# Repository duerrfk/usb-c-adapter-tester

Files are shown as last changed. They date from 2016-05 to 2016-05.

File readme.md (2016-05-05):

USB-C-Adapter-Tester is a device to test USB-C-to-USB-A/Micro-USB cables and adapters for conformity with the USB standard. Such USB-C adapters should use a 56k resistor connecting the 5 V line to the CC (Channel Configuration) line to signal to the downstream device (e.g., smartphone) that it should not draw more than standard USB power. However, some cables and adapters use smaller resistor values resulting in excessive current drawn by the downstream USB-C device, which might damage the upstream USB device providing power.

USB-C-Adapter-Tester consists of a hardware and a software part:

* circuit board (PCB) for connecting the USB-C cable/adapter under test 
* software based on the Arduino platform

Eagle files and PDFs for the hardware (schematics, board layout) can be found in folder `pcb`. The software can be found in folder `src`.

# Hardware

The tester hardware as depicted in the figures below consists of a microcontroller (Atmega 328p; same chip as the Arduino UNO) featuring an Analog-to-Digital Converter (ADC). The ADC measures the voltage drop along a 5.1k resistor (actually, two separate 5.1k resistors on different channels of the ADC since USB-C features two CC lines so you can plug-in the USB-C cable either way). Knowing the resistance and the voltage drop measured by the ADC, the microcontroller calculates the current (ICC) flowing on the CC line. If ICC is within the specified range (80 uA +- 20 % according to the standard), an LED signaling a "good" cable is turned on from an GPIO pin. If it is outside the range, another LED signaling a "bad" cable is turned on.

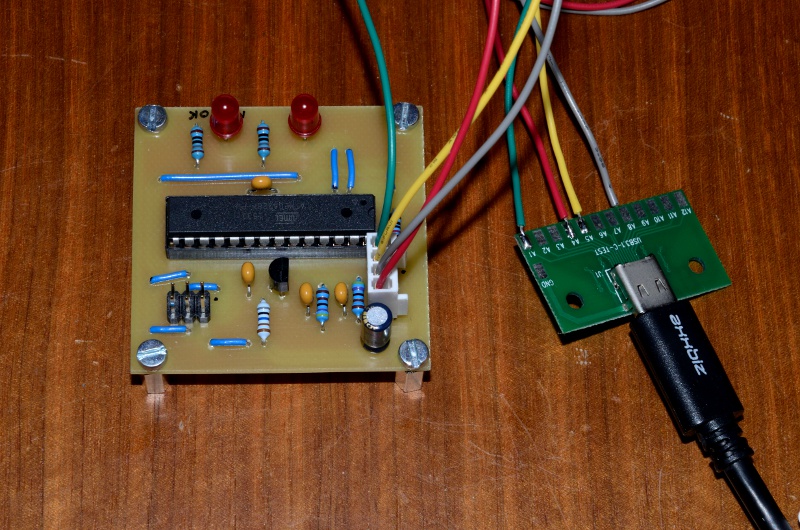
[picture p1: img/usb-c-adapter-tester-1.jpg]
USB-C Tester Device

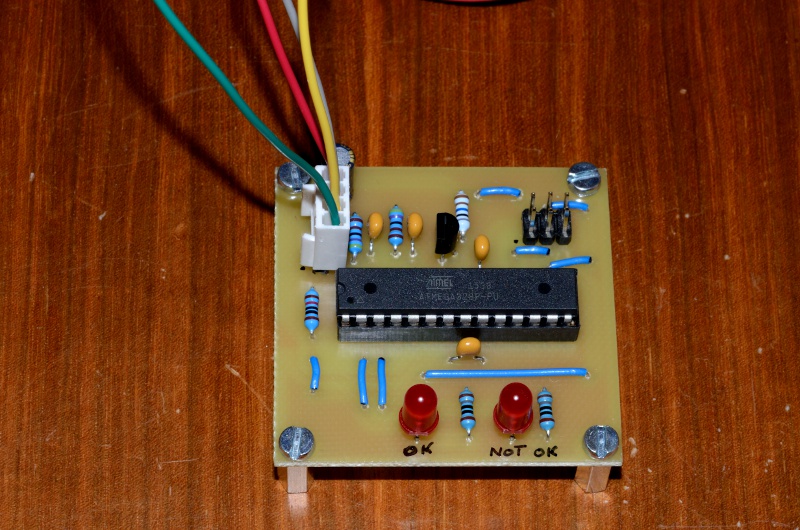
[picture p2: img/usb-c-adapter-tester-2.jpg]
USB-C Tester Device


The cable to be checked is connected to an USB host or charger to power the microcontroller. The good old Atmega 328p can be powered from 5V, which is the voltage provided by standard USB-A and Micro-USB. 

Since the internal voltage reference of the Atmega might not be very precise, an external 2.5 V voltage reference diode is used as reference for the ADC. 

As soon as the cable under test is plugged in, the microcontroller starts measuring the voltage drop along the 5.1k resistor using the ADC, translates the voltage to current (R = V/I), compares the measured current to the allowed current range (80 uA +- 20 %), and switches on the corresponding "good" or "bad cable" LED.

# Programming the Microcontroller

The code is implemented for the Arduino platform. 

The device is programmed through an in-system programmer port (6 pin ISP) with the following standard layout:

    MISO <-- 1 2 --> VCC
     SCK <-- 3 4 --> MOSI
     RST <-- 5 6 --> GND

To prepare the Atmega, program the following fuses (note that "0" means 
that the fuse is programmed):

* CKSEL = 0010: use internal 8 MHz RC oscillator
* CKDIV8 = 1: 8 MHz system clock (do not divide the 8 MHz internal clock by 8)
* SPIEN = 0: enable serial programming
* BODLEVEL = 101: brown-out detection set to 2.7 V
* SUT = 00: lowest possible startup time (6 CK from power-down; since we use
  BOD, we do not need additional waiting time for the power source to come up)
    
Using avrdude, the command looks like this (you might need
to execute this command as root):

    $ avrdude -c usbasp -p m328p -U lfuse:w:0xc2:m -U hfuse:w:0xd9:m -U efuse:w:0x05:m

Make sure to compile your code for the correct board (Atmega 328p at 8 MHz). In the repository, 
you will find a suitable board definition for the Arduino IDE (see folder 
`board_definition`). Copy the directory `atmega328_8MHz` into the folder 
`hardware` in your Arduino sketchbook. Then you should find and select the 
board  called `ATmega328P @ 8 MHz` under the menu item `Tools/Board`. 

Compiling generates a hex file that you need to program the Atmega. This hex 
file is a little hidden in the temporary build directory of the Arduino
IDE. If you use Linux  and Arduino IDE 1.6, have a look at the `/tmp` 
directory. After hitting the  compile button in the Arduino IDE, search for the
latest hex file called `usb-c-adapter-tester.cpp.hex` in a temporary directory named `/tmp/build...`. If you have found the hex file, you can flash it using avrdude (again, you might need to be root):

    $ avrdude -p m328p -c usbasp -v -U flash:w:/tmp/build6535101126624677692.tmp/usb-c-adapter-tester.cpp.hex

# Licensing

USB-C-Adapter-Tester uses two licenses for open hardware and software, respectively:

* The software (source code) is licensed under the Apache License 2.0
* The hardware (schematic diagrams, circuit board layouts, hardware documentation) is licensed under the CERN Open Hardware Licence v1.2

Both licenses are included in the repository.

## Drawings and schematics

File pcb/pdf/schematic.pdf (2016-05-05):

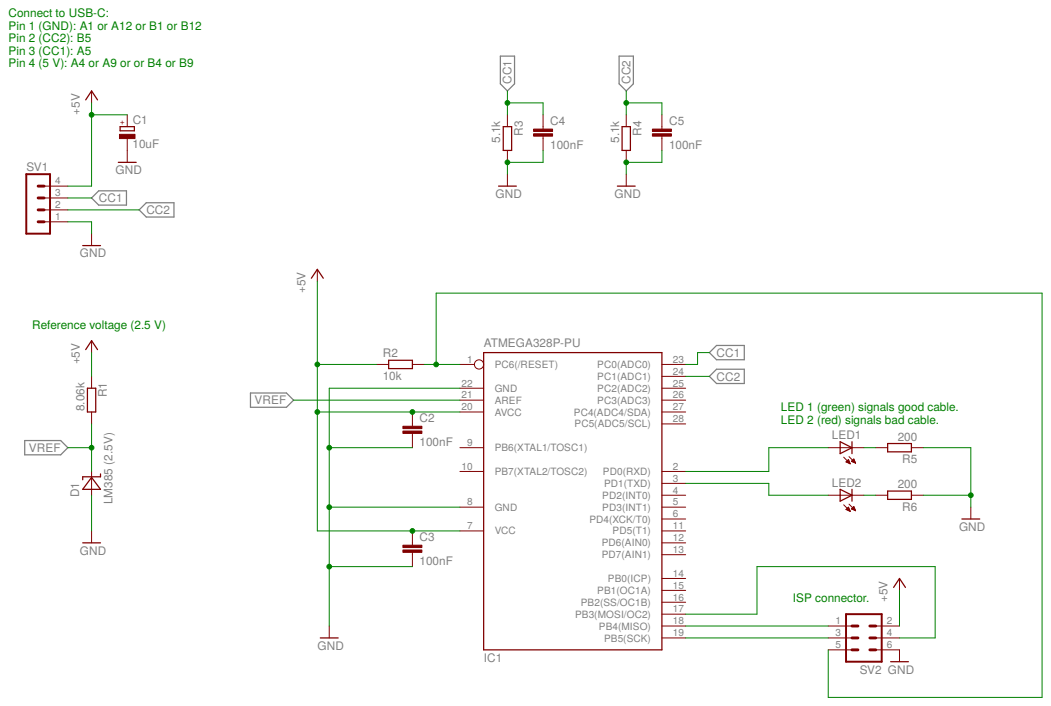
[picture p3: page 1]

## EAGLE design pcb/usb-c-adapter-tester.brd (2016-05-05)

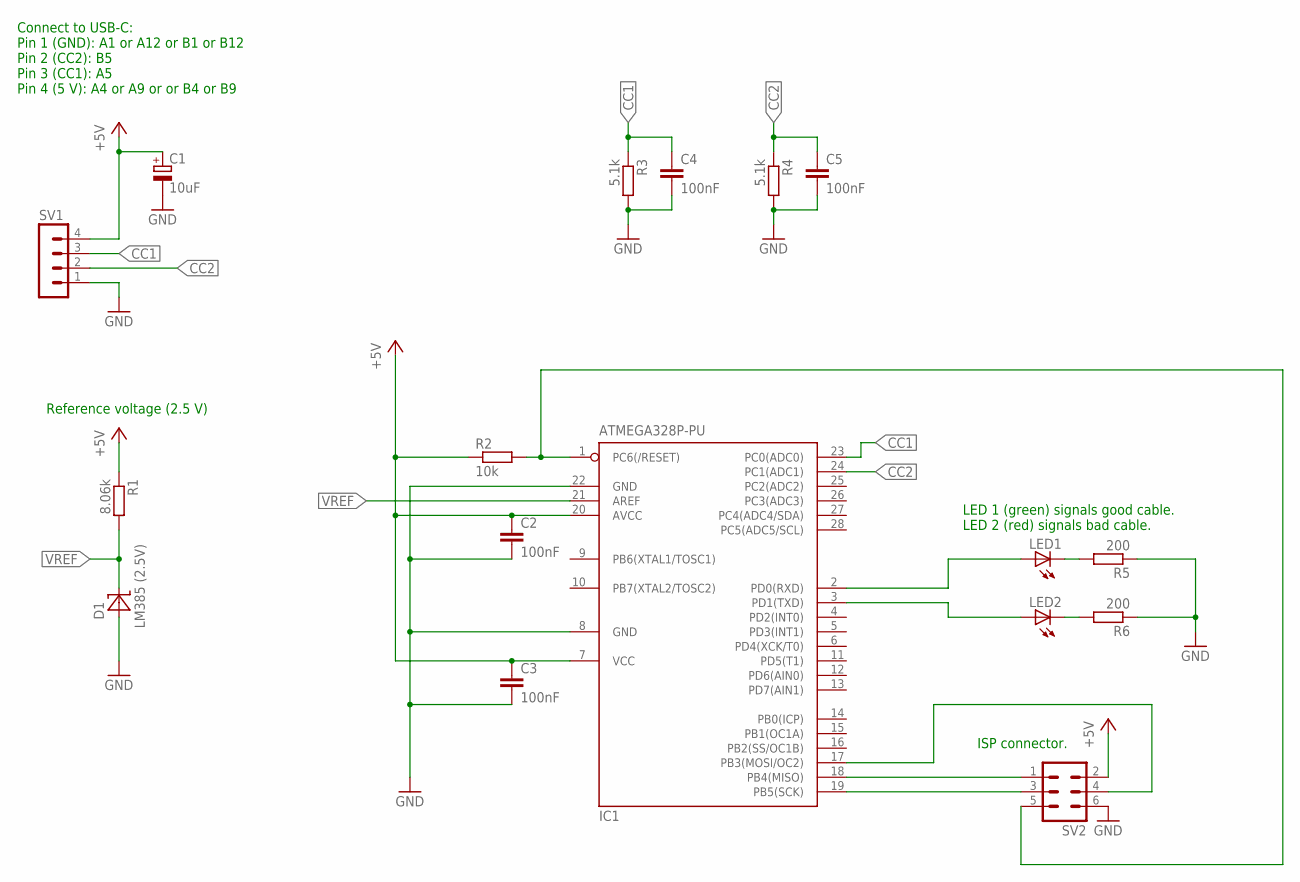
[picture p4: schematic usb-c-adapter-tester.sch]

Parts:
C1: 10uF; E2,5-5
C2, C3, C4, C5: 100nF; C050-024X044
D1: LM385 (2.5V); TO-92
IC1: ATMEGA328P-PU; DIL28-3
LED1, LED2: LED5MM
R1: 8.06k; 0207/7
R2: 10k; 0207/7
R3, R4: 5.1k; 0207/7
R5, R6: 200; 0207/7
SV1: MA04-1
SV2: MA03-2

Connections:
CC1: C4.1, IC1.23 (PC0(ADC0)), R3.1, SV1.3
CC2: C5.1, IC1.24 (PC1(ADC1)), R4.1, SV1.2
GND: C1.-, C2.2, C3.2, C4.2, C5.2, D1.+, IC1.8 (GND), IC1.22 (GND), R3.2, R4.2, R5.1, R6.1, SV1.1, SV2.6
unnamed: IC1.1 (PC6(/RESET)), R2.2, SV2.5
unnamed: LED1.K (C), R5.2
unnamed: LED2.K (C), R6.2
unnamed: IC1.17 (PB3(MOSI/OC2)), SV2.4
unnamed: IC1.2 (PD0(RXD)), LED1.A
unnamed: IC1.18 (PB4(MISO)), SV2.1
unnamed: IC1.3 (PD1(TXD)), LED2.A
unnamed: IC1.19 (PB5(SCK)), SV2.3
unnamed: C1.+, C2.1, C3.1, IC1.7 (VCC), IC1.20 (AVCC), R1.1, R2.1, SV1.4, SV2.2
VREF: D1.-, IC1.21 (AREF), R1.2

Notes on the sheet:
Connect to USB-C: Pin 1 (GND): A1 or A12 or B1 or B12 Pin 2 (CC2): B5 Pin 3 (CC1): A5 Pin 4 (5 V): A4 or A9 or or B4 or B9
LED 1 (green) signals good cable. LED 2 (red) signals bad cable.
ISP connector.
Reference voltage (2.5 V)

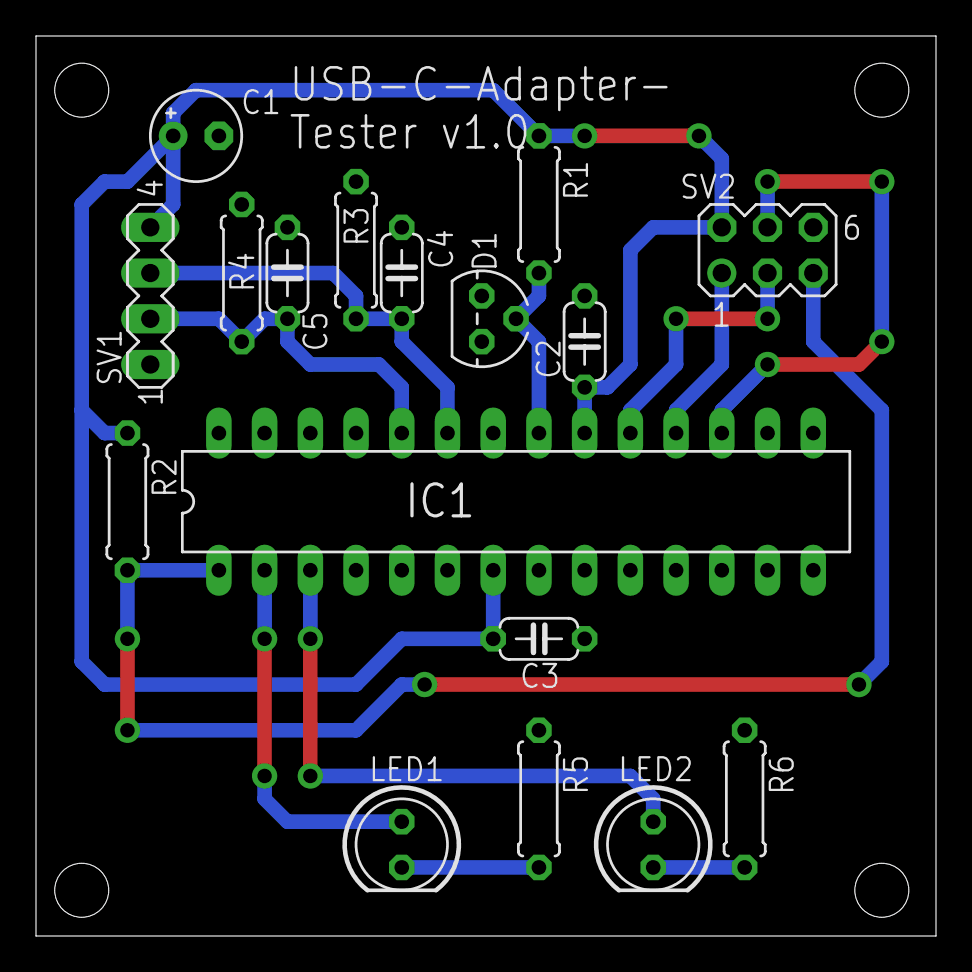
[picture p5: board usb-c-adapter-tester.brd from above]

Board: 2 copper layers, 50.0 x 50.0 mm, 17 parts (0 on the bottom side), 13 nets.

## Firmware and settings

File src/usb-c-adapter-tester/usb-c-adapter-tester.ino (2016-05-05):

/**
 * This file is part of USB-C-Adapter-Tester.
 * 
 * Copyright 2016 Frank Duerr
 *
 * Licensed under the Apache License, Version 2.0 (the "License");
 * you may not use this file except in compliance with the License.
 * You may obtain a copy of the License at
 * 
 * http://www.apache.org/licenses/LICENSE-2.0
 * 
 * Unless required by applicable law or agreed to in writing, software
 * distributed under the License is distributed on an "AS IS" BASIS,
 * WITHOUT WARRANTIES OR CONDITIONS OF ANY KIND, either express or implied.
 * See the License for the specific language governing permissions and
 * limitations under the License.
 */

#define PIN_LED_OK 0
#define PIN_LED_NOTOK 1

#define PIN_CC1 A0
#define PIN_CC2 A1

// Resistance of shunt resistor for measuring current [Ohm]
const float R_shunt = 5100.0f;

// Reference voltage of ADC [V]
const float V_ref = 2.5f;

// According to the USB-C standard, "Default USB power" is signaled by 
// current I = 80 uA +- 20 % on CC line. This current range leads to the 
// following allowed voltage range measured along the shunt.
const float V_min = R_shunt*80e-6f * 0.8f;
const float V_max = R_shunt*80e-6f * 1.2f;

// ADC counts of 10 bit ADC corresponding to V_min (low threshold) 
// and V_max (high threshold) 
const uint16_t Low_threshold = (uint16_t) (((V_min/V_ref) * 1023.0f) + 0.5f);
const uint16_t High_threshold = (uint16_t) (((V_max/V_ref) * 1023.0f) + 0.5f);

void setup() 
{
    // Configure LED pins as output
    pinMode(PIN_LED_OK, OUTPUT);
    pinMode(PIN_LED_NOTOK, OUTPUT);
    digitalWrite(PIN_LED_OK, LOW);
    digitalWrite(PIN_LED_NOTOK, LOW);

    // Configure ADC.    
    // Use external voltage reference (2.5 V) for ADC.
    analogReference(EXTERNAL);
    // Perform dummy ADC reading for the following reason:
    // "The first ADC conversion result after switching reference 
    // voltage source may be inaccurate, and the user is advised 
    // to discard this result." [ATmega 48/88/168/326 datasheet]
    uint16_t dummy = analogRead(PIN_CC1);

    // To be really save, give some extra time to stabilize.
    delay(500);
}

void loop() 
{
    // Sample both CC pins
    uint16_t sampleCC1 = analogRead(PIN_CC1);
    uint16_t sampleCC2 = analogRead(PIN_CC2);
    
    // Only one CC pin is connected to host; the other is pulled low.
    // -> use the sample with higher value
    uint16_t sampleCC = sampleCC1 > sampleCC2 ? sampleCC1 : sampleCC2;

    if (sampleCC >= Low_threshold && sampleCC <= High_threshold) {
        digitalWrite(PIN_LED_OK, HIGH);
        digitalWrite(PIN_LED_NOTOK, LOW);
    } else {
        digitalWrite(PIN_LED_OK, LOW);
        digitalWrite(PIN_LED_NOTOK, HIGH);
    }
    
    // About 10 samples per second is more than enough.
    delay(100);
}

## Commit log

2016-05-05 Initial check-in
    [usb-c-adapter-tester.brd, usb-c-adapter-tester.sch]
2016-05-05 Changed board definition
